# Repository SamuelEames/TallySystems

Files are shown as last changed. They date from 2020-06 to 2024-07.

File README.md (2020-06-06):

# vMixTally
Tally light system for vMix using Arduino USB MIDI controller, transmitting tally light data to receiver modules on cameras using NRF24L01 radios

## MIDI Map

Notes
* Use midi note value to set colour of LEDs on tally lights

* Channel = 2

Data from vMix
* Preview <Input Number> Note 000-031
* Program <Input Number> Note 100-131
* Streaming

Data from BMD
 * Preview <Input Number>
 * Program <Input Number>
 * AUX 	   <Input Number>

BMD Inputs
1-8
MP 1-2
Col 1-2
FTB

Tally Light Colours
|			| 			| BMD		|			|			|
| --- | --- | --- | --- | --- |
|			|			| No Signal	| Program	| Preview	| AUX
| vMix 		| No Signal	| NA		| Yellow	| Blue 		|
|			| Program	| Yellow	| Red		| Green 	|
|			| Preview	| Blue		| Green		| Off 		|

# Resources
BMD-Arduino interface
https://github.com/mathijsk/Arduino-Library-for-ATEM-Switchers 

Insanely cool company
https://www.skaarhoj.com/various/atem-arduino-case-stories/
https://www.skaarhoj.com/support/manual/

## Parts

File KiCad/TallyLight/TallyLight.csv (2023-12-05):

Source: | C:\Users\samue\OneDrive\Documents\ELECTRONICS_PROJECTS\TallySystems\KiCad\TallyLight\TallyLight.kicad_sch
Date: | 9/11/2023 0:10:53
Tool: | Eeschema 7.0.5
Generator: | C:\Program Files\KiCad\7.0\bin\scripting\plugins/bom_csv_grouped_by_value.py
Component Count: | 48
Collated Components:
Item | Qty | Reference(s) | Value | LibPart | Footprint | Datasheet | DNP | Description | Height | Manufacturer_Name | Manufacturer_Part_Number | Mouser Part Number | Mouser Price/Stock
1 | 3 | 3V1, 5V1, LED1 | LED | Device:LED | LED_SMD:LED_0805_2012Metric | ~
2 | 11 | C1, C2, C3, C4, C5, C6, C7, C8, C14, C15, C16 | 104 | SamacSys_Parts:C0805C104M5RACTU | SamacSys_Parts:C0805 | https://content.kemet.com/datasheets/KEM_C1002_X7R_SMD.pdf |  | SMD Comm X7R, Ceramic, 0.1 uF, 20%, 50 VDC, 125 VDC, 125?C, -55?C, X7R, SMD, MLCC, Temperature Stable, Class II, 2.5 % , 10 GOhms, 11 mg, 0805, 2mm, 1.25mm, 0.78mm, 0.75mm, 0.5mm, 4000, 78 Weeks, 80 | 1.1 | KEMET | C0805C104M5RACTU | 80-C0805C104M5R | https://www.mouser.co.uk/ProductDetail/KEMET/C0805C104M5RACTU?qs=VOOUd%252Bza08qHu13WgNByHQ%3D%3D
3 | 2 | C9, C11 | 105 | SamacSys_Parts:CL21B105KBFNNNG | SamacSys_Parts:CAPC2012X135N | https://datasheet.datasheetarchive.com/originals/distributors/Datasheets-DGA8/2478774.pdf |  | Cap Ceramic 1uF 50V X7R 10% Pad SMD 0805 125C T/R | 1.35 | Samsung Electro-Mechanics | CL21B105KBFNNNG | 187-CL21B105KBFNNNG | https://www.mouser.co.uk/ProductDetail/Samsung-Electro-Mechanics/CL21B105KBFNNNG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
4 | 1 | C10 | 471 | SamacSys_Parts:C0805C471K5RACTU | SamacSys_Parts:C0805 | https://content.kemet.com/datasheets/KEM_C1002_X7R_SMD.pdf |  | SMD Comm X7R, Ceramic, 470 pF, 10%, 50 VDC, 125 VDC, 125?C, -55?C, X7R, SMD, MLCC, Temperature Stable, Class II, 2.5 % , 100 GOhms, 11 mg, 0805, 2mm, 1.25mm, 0.78mm, 0.75mm, 0.5mm, 4000, 78 Weeks, 80 | 1.1 | KEMET | C0805C471K5RACTU | 80-C0805C471K5R | https://www.mouser.co.uk/ProductDetail/KEMET/C0805C471K5RACTU?qs=zLJ08xwufm6Yml9V9rLpFw%3D%3D
5 | 2 | C12, C13 | 106 | SamacSys_Parts:GRM188D71A106MA73J | SamacSys_Parts:CAPC1608X90N | https://psearch.en.murata.com/capacitor/product/GRM188D71A106MA73%23.html |  | Capacitor GRM18_0.20 L=1.6mm W=0.8mm T=0.8mm | 0.9 | Murata Electronics | GRM188D71A106MA73J | 81-GRM188D71A106MA3J | https://www.mouser.co.uk/ProductDetail/Murata-Electronics/GRM188D71A106MA73J?qs=hNud%2FORuBR3g0t9KhbQaoQ%3D%3D
6 | 2 | C17, C18 | 22p | SamacSys_Parts:C0805C220K5HACTU | SamacSys_Parts:C0805 | https://content.kemet.com/datasheets/KEM_C1007_X8R_ULTRA_150C_SMD.pdf |  | SMD Comm X8R HT150C, Ceramic, 22 pF, 10%, 50 VDC, 125 VDC, 150C, -55C, X8R, SMD, MLCC, High Temperature, Ultra-Stable, 2.5 % , 100 GOhms, 11 mg, 0805, 2mm, 1.25mm, 0.78mm, 0.75mm, 0.5mm, 4000, 78 Weeks | 1.1 | KEMET | C0805C220K5HACTU | 80-C0805C220K5HACTU | https://www.mouser.co.uk/ProductDetail/KEMET/C0805C220K5HACTU?qs=W0yvOO0ixfEHOdsIsVM%2FuQ%3D%3D
7 | 1 | IC1 | TC1263-3.3VOATR | SamacSys_Parts:TC1263-3.3VOATR | SamacSys_Parts:SOIC127P600X175-8N | http://ww1.microchip.com/downloads/en/DeviceDoc/21374D.pdf |  | LDO Voltage Regulators 500mA Fixed Out Adj | 1.75 | Microchip | TC1263-3.3VOATR | 579-TC1263-3.3VOATR | https://www.mouser.co.uk/ProductDetail/Microchip-Technology/TC1263-33VOATR?qs=JKWmWPM4binFIJC0VNJYCQ%3D%3D
8 | 1 | IC2 | VEML7700-TT | SamacSys_Parts:VEML7700-TT | SamacSys_Parts:VEML7700 | https://www.arrow.com/en/products/veml7700-tt/vishay |  | 16Bit Ambient Light Sensor I2C 6.8x2.3mm |  | Vishay | VEML7700-TT | 78-VEML7700-TT | https://www.mouser.co.uk/ProductDetail/Vishay-Semiconductors/VEML7700-TT?qs=BcfjnG7NVaXdL6DJFdWbdw%3D%3D
9 | 1 | IC3 | ATMEGA328PB-AU | SamacSys_Parts:ATMEGA328PB-AU | SamacSys_Parts:QFP80P900X900X120-32N |  |  | ATMEL - ATMEGA328PB-AU - MCU, 8BIT, ATMEGA, 20MHZ, TQFP-32 | 1.2 | Microchip | ATMEGA328PB-AU | 556-ATMEGA328PB-AU | https://www.mouser.co.uk/ProductDetail/Microchip-Technology/ATMEGA328PB-AU?qs=jy4bLUHv09hbFONgGrqPbw%3D%3D
10 | 1 | J1 | USB4125-GF-A-0190 | SamacSys_Parts:USB4125-GF-A-0190 | SamacSys_Parts:USB4125GFA0190 |  |  | USB Connectors USB C Rec GF RA 6P SMT TH Stakes 1.9mm |  | GCT (GLOBAL CONNECTOR TECHNOLOGY) | USB4125-GF-A-0190 | 640-USB4125-GF-A-190 | https://www.mouser.co.uk/ProductDetail/GCT/USB4125-GF-A-0190?qs=QNEnbhJQKvbCz4hEJBS24w%3D%3D
11 | 1 | J2 | Conn_01x01_Pin | Connector:Conn_01x01_Pin | Connector_PinSocket_2.54mm:PinSocket_1x01_P2.54mm_Vertical | ~
12 | 1 | J3 | Conn_01x06_Pin | Connector:Conn_01x06_Pin | Connector_PinHeader_2.54mm:PinHeader_1x06_P2.54mm_Vertical | ~
13 | 1 | J4 | Conn_01x03_Pin | Connector:Conn_01x03_Pin | Connector_PinHeader_2.54mm:PinHeader_1x03_P2.54mm_Vertical | ~
14 | 1 | Q1 | BSS138DW-7-F | SamacSys_Parts:BSS138DW-7-F | SamacSys_Parts:SOT65P210X110-6N |  |  | MOSFET Dual N-Channel 50V 0.2A SOT363 Diodes Inc BSS138DW-7-F Dual N-channel MOSFET Transistor, 0.2 A, 50 V, 6-Pin SOT-363 | 1.1 | Diodes Inc. | BSS138DW-7-F | 621-BSS138DW-F | https://www.mouser.co.uk/ProductDetail/Diodes-Incorporated/BSS138DW-7-F?qs=rGAXPo9uwV10UlZnPRLyGg%3D%3D
15 | 2 | R1, R2 | 5K1 | Device:R | Samuel_Library:R_0805_2012Metric_Pad1.20x1.40mm_HandSolder | ~
16 | 1 | R3 | 100K | Device:R | Samuel_Library:R_0805_2012Metric_Pad1.20x1.40mm_HandSolder | ~
17 | 1 | R4 | 130R | Device:R | Samuel_Library:R_0805_2012Metric_Pad1.20x1.40mm_HandSolder | ~
18 | 2 | R5, R6 | 300R | Device:R | Samuel_Library:R_0805_2012Metric_Pad1.20x1.40mm_HandSolder | ~
19 | 1 | RN1 | 10K | SamacSys_Parts:YC124-JR-0710KL | SamacSys_Parts:YC124JR0710KL | https://www.yageo.com/upload/media/product/productsearch/datasheet/rchip/PYu-YC_TC_group_51_RoHS_L_9.pdf |  | 10k Ohm +/-5% 62.5mW Power Per Element Isolated 4 Resistor Network/Array +/-200ppm/C 0804, Convex, Long Side Terminals | 0.55 | YAGEO | YC124-JR-0710KL | 603-YC124-JR-0710KL | https://www.mouser.co.uk/ProductDetail/YAGEO/YC124-JR-0710KL?qs=o9qB%2F%252BVTi4UUU%2FolE1vUew%3D%3D
20 | 1 | SET1 | TS02-66-50-BK-260-SCR-D | SamacSys_Parts:TS02-66-50-BK-260-SCR-D | SamacSys_Parts:TS026650BK260SCRD | https://www.cuidevices.com/product/resource/ts02.pdf |  | Tactile Switches 6 x 6 mm, 5 mm Act Height, 260 gf, Black, Short Crimped, Through Hole, SPST, | 5.2 | CUI Devices | TS02-66-50-BK-260-SCR-D | 179-TS026650BK260SCR | https://www.mouser.co.uk/ProductDetail/CUI-Devices/TS02-66-50-BK-260-SCR-D?qs=A6eO%252BMLsxmQtNldP04biKA%3D%3D
21 | 1 | TALLY#1 | SD-1210 | SamacSys_Parts:SD-1210 | SamacSys_Parts:SD1210 | https://www.mouser.ch/datasheet/2/972/sd_1000_26sd_2000-1827479.pdf |  | Coded Rotary Switches dip rotary code hex, real code, top adj. with + slot | 4.2 | NIDEC COPAL | SD-1210 | 229-SD-1210 | https://www.mouser.co.uk/ProductDetail/Nidec-Copal/SD-1210?qs=XeJtXLiO41R8TV%2F4jbbpgQ%3D%3D
22 | 1 | U1 | LED 1 | Samuel_Library:SK6812_SIDE-A | Samuel_Library:SK6812_SIDE-A
23 | 1 | U2 | LED 2 | Samuel_Library:SK6812_SIDE-A | Samuel_Library:SK6812_SIDE-A
24 | 1 | U3 | LED 3 | Samuel_Library:SK6812_SIDE-A | Samuel_Library:SK6812_SIDE-A
25 | 1 | U4 | LED 4 | Samuel_Library:SK6812_SIDE-A | Samuel_Library:SK6812_SIDE-A
26 | 1 | U5 | LED 5 | Samuel_Library:SK6812_SIDE-A | Samuel_Library:SK6812_SIDE-A
27 | 1 | U6 | LED 6 | Samuel_Library:SK6812_SIDE-A | Samuel_Library:SK6812_SIDE-A
28 | 1 | U7 | LED 7 | Samuel_Library:SK6812_SIDE-A | Samuel_Library:SK6812_SIDE-A
29 | 1 | U8 | LED 8 | Samuel_Library:SK6812_SIDE-A | Samuel_Library:SK6812_SIDE-A
30 | 1 | U9 | NRF24L01 | MySensors:NRF24L01 | MySensors:NRF24L01-SMD
31 | 1 | Y1 | 16M | SamacSys_Parts:ABLS-16.000MHz-16-A-4-H-T | SamacSys_Parts:ABLS | https://abracon.com/Resonators/abls.pdf |  | Oscillator MEMS 120MHz +/-10ppm (Stability) 15pF LVCMOS 55% 1.8V/2.5V/3.3V Automotive 4-Pin QFN SMD T/R |  | ABRACON | ABLS-16.000MHz-16-A-4-H-T | 815-LS16000MHZ16A4HT | https://www.mouser.co.uk/ProductDetail/ABRACON/ABLS-16.000MHZ-16-A-4-H-T?qs=vLWxofP3U2z6hhU1at4Vrw%3D%3D

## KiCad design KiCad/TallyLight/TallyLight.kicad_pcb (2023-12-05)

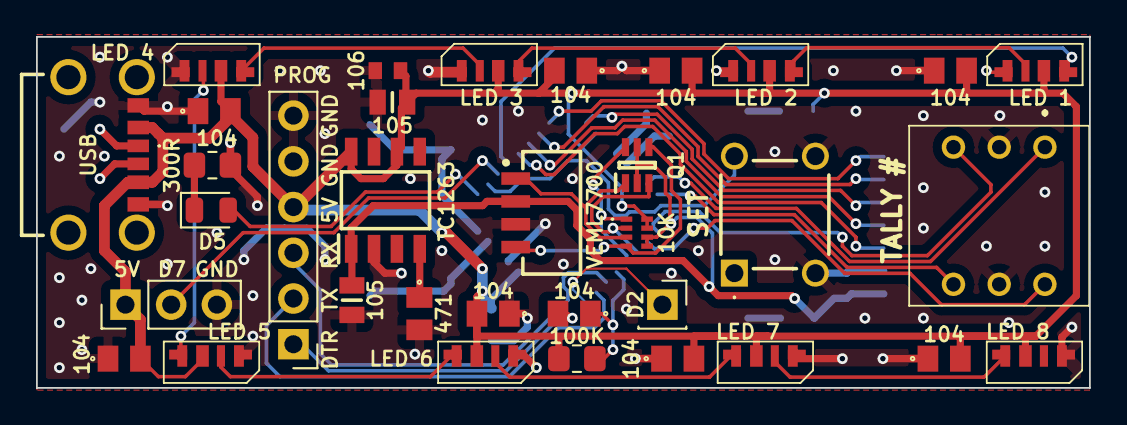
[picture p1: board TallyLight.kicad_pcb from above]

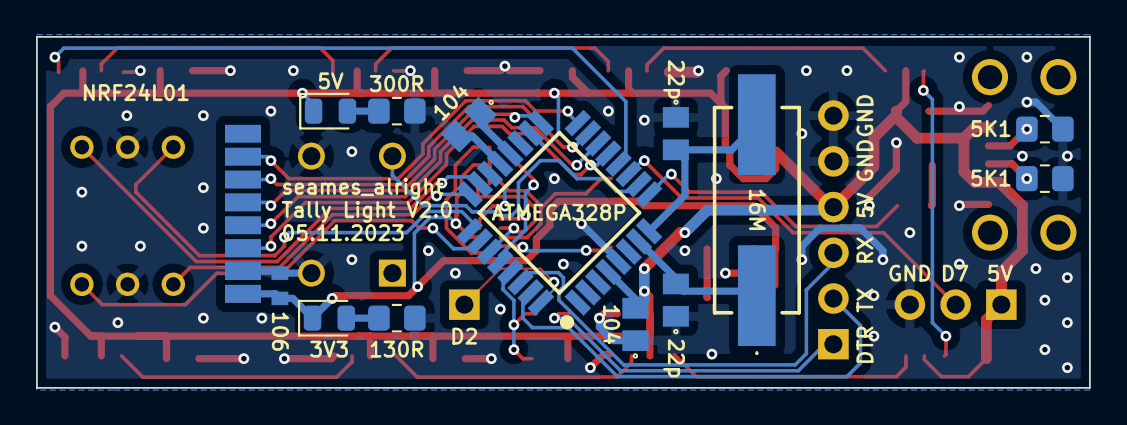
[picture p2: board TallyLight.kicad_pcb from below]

Board: 2 copper layers, 58.5 x 19.5 mm, 48 parts (14 on the bottom side), 41 nets.

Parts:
3V3, 5V: LED; LED_0805_2012Metric
16M: 16M; ABLS
ATMEGA328P: ATMEGA328PB-AU; QFP80P900X900X120-32N
C1, C2, C3, C4, C5, C6, C7, C8, C14, C15, C16: 104; C0805
C9, C11: 105; CAPC2012X135N
C10: 471; C0805
C12, C13: 106; CAPC1608X90N
C17, C18: 22p; C0805
D2: Conn_01x01_Pin; PinSocket_1x01_P2.54mm_Vertical
D5: LED; LED_0805_2012Metric
J4: Conn_01x03_Pin; PinHeader_1x03_P2.54mm_Vertical
NRF24L01: NRF24L01; NRF24L01-SMD
PROG: Conn_01x06_Pin; PinHeader_1x06_P2.54mm_Vertical
Q1: BSS138DW-7-F; SOT65P210X110-6N
R1, R2: 5K1; R_0805_2012Metric_Pad1.20x1.40mm_HandSolder
R3: 100K; R_0805_2012Metric_Pad1.20x1.40mm_HandSolder
R4: 130R; R_0805_2012Metric_Pad1.20x1.40mm_HandSolder
R5, R6: 300R; R_0805_2012Metric_Pad1.20x1.40mm_HandSolder
RN1: 10K; YC124JR0710KL
SET: TS02-66-50-BK-260-SCR-D; TS026650BK260SCRD
TALLY #: SD-1210; SD1210
TC1263: TC1263-3.3VOATR; SOIC127P600X175-8N
U1: LED 1; SK6812_SIDE-A
U2: LED 2; SK6812_SIDE-A
U3: LED 3; SK6812_SIDE-A
U4: LED 4; SK6812_SIDE-A
U5: LED 5; SK6812_SIDE-A
U6: LED 6; SK6812_SIDE-A
U7: LED 7; SK6812_SIDE-A
U8: LED 8; SK6812_SIDE-A
USB: USB4125-GF-A-0190; USB4125GFA0190
VEML7700: VEML7700-TT; VEML7700

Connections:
+3V3: 3V3.1 (K), C9.1, C12.1, NRF24L01.2 (VCC), Q1.2 (G2), Q1.5 (G1), RN1.5, RN1.6, TC1263.1 (VOUT), VEML7700.2 (VDD)
+5V: 5V.1 (K), ATMEGA328P.4 (VCC), ATMEGA328P.18 (AVCC), C1.2, C2.2, C3.2, C4.2, C5.2, C6.2, C7.2, C8.2, C11.1, C13.1, C14.2, J4.1, PROG.4, R3.1, RN1.7, RN1.8, TC1263.6 (~SHDN), TC1263.8 (VIN), U1.2 (VDD), U2.2 (VDD), U3.2 (VDD), U4.2 (VDD), U5.2 (VDD), U6.2 (VDD), U7.2 (VDD), U8.2 (VDD), USB.A9 (VBUS_1), USB.B9 (VBUS_2)
/BTN: ATMEGA328P.10 ((OC0A/PTCXY/AIN0)_PD6), SET.2 (NO_2)
/DTR: C15.2, PROG.1
/HEX_1: ATMEGA328P.23 (PC0_(ADC0/PTCY/MISO1)), TALLY #.1
/HEX_2: ATMEGA328P.24 (PC1_(ADC1/PTCY/SCK1)), TALLY #.2
/HEX_4: ATMEGA328P.25 (PC2_(ADC2/PTCY)), TALLY #.4
/HEX_8: ATMEGA328P.26 (PC3_(ADC3/PTCY)), TALLY #.8
/LED: ATMEGA328P.9 ((OC0B/T1/PTCXY)_PD5), D5.2 (A)
/LED_DATA: ATMEGA328P.12 ((ICP1/CLKO/PTCXY)_PB0), U1.1 (DIN)
/LED_DATA_2: ATMEGA328P.11 ((PTCXY/AIN1)_PD7), J4.2
/MISO: ATMEGA328P.16 ((MISO0/RXD1/PTCXY)_PB4), NRF24L01.7 (MISO)
/MOSI: ATMEGA328P.15 ((MOSI0/TXD1/OC2A/PTCXY)_PB3), NRF24L01.6 (MOSI)
/RF_CE: ATMEGA328P.13 ((OC1A/PTCXY)_PB1), NRF24L01.3 (CE)
/RF_CSN: ATMEGA328P.14 ((~SS0/OC1B/PTCXY)_PB2), NRF24L01.4 (CSN)
/RST: ATMEGA328P.29 (PC6_(~RESET)), C15.1, R3.2
/RXI: ATMEGA328P.30 (PD0_(PTCXY/OC3A/RXD0)), PROG.3
/SCK: ATMEGA328P.17 (PB5_(PTCXY/XCK0/SCK0)), NRF24L01.5 (SCK)
/SCL: ATMEGA328P.28 (PC5_(ADC5/PTCY/SCL0)), Q1.6 (D2), RN1.1
/SCL_3V: Q1.1 (S2), RN1.3, VEML7700.1 (SCL)
/SDA: ATMEGA328P.27 (PC4_(ADC4/PTCY/SDA0)), Q1.3 (D1), RN1.2
/SDA_3V: Q1.4 (S1), RN1.4, VEML7700.4 (SDA)
/TXO: ATMEGA328P.31 (PD1_(PTCXY/OC4A/TXD0)), PROG.2
/XTAL1: 16M.1, ATMEGA328P.7 ((XTAL1/TOSC1)_PB6), C17.2
/XTAL2: 16M.2, ATMEGA328P.8 ((XTAL2/TOSC2)_PB7), C18.2
GND: ATMEGA328P.5 (GND_1), ATMEGA328P.21 (GND_2), C1.1, C2.1, C3.1, C4.1, C5.1, C6.1, C7.1, C8.1, C9.2, C10.2, C11.2, C12.2, C13.2, C14.1, C16.2, C17.1, C18.1, J4.3, NRF24L01.1 (GND), PROG.5, PROG.6, R1.2, R2.2, R4.1, R5.1, R6.1, SET.3 (COM_1), SET.4 (COM_2), TALLY #.C1, TALLY #.C2, TC1263.2 (GND), U1.4 (GND), U2.4 (GND), U3.4 (GND), U4.4 (GND), U5.4 (GND), U6.4 (GND), U7.4 (GND), U8.4 (GND), USB.A12 (GND_1), USB.B12 (GND_2), VEML7700.3 (GND)
unnamed: 3V3.2 (A), R4.2
unnamed: 5V.2 (A), R5.2
unnamed: C10.1, TC1263.4 (BYPASS)
unnamed: ATMEGA328P.20 (AREF), C16.1
unnamed: ATMEGA328P.32 (PD2_(PTCXY/INT0/OC3B/OC4B)), D2.1
unnamed: R1.1, USB.A5 (CC1)
unnamed: R2.1, USB.B5 (CC2)
unnamed: D5.1 (K), R6.2
unnamed: U1.3 (DOUT), U2.1 (DIN)
unnamed: U2.3 (DOUT), U3.1 (DIN)
unnamed: U3.3 (DOUT), U4.1 (DIN)
unnamed: U4.3 (DOUT), U5.1 (DIN)
unnamed: U5.3 (DOUT), U6.1 (DIN)
unnamed: U6.3 (DOUT), U7.1 (DIN)
unnamed: U7.3 (DOUT), U8.1 (DIN)

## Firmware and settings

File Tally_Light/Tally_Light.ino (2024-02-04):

/* Tally Light

11/10/2023 - started major updates!
  * TODO
    * DONE! - Hex switch to select tally number
    * Light sensor to set brightness automatically
    * Button to set channel
      * Hold button while powering on, then use hex switch to select channel.
      * Channel is saved to EEPROM 10s after no changes
      * Either power cycle to get out of settings mode, OR automatically restart after the 10s
    * When on tally '0' show pattern on LEDs each time signal is received

  * Changed MCU to save costs on units - using Atmega328 instead of Atmega32u4


TODO 
  * Add pixel output for optional tally light up number block on top of camera
      * Or it could just use the same output and override the original one, like how headphone ports switch inhibit speakers when headphones are used
      * Be careful not to short out PSU with whatever connection is used though.



*/



// SETUP DEBUG MESSAGES
// #define DEBUG   //If you comment this line, the DPRINT & DPRINTLN lines are defined as blank.
#ifdef DEBUG
  #define DPRINT(...)   Serial.print(__VA_ARGS__)   //DPRINT is a macro, debug print
  #define DPRINTLN(...) Serial.println(__VA_ARGS__) //DPRINTLN is a macro, debug print with new line
#else
  #define DPRINT(...)                       //now defines a blank line
  #define DPRINTLN(...)                     //now defines a blank line
#endif


#include "FastLED.h"
#include "RF24.h"
#include "ENUMVars.h"
#include "Adafruit_VEML7700.h"


///////////////////////// IO /////////////////////////

// ///////////////////////// Atmega32u4 
// #define RF_CSN_PIN    18
// #define RF_CE_PIN     19

// #define LED_F_PIN     20
// #define LED_B_PIN     21


///////////////////////// Atmega328 
// Radio
#define RF_CE_PIN     9     // 13 - PB1
#define RF_CSN_PIN    10    // 14 - PB2
// SCK  - 17 PB5
// MOSI - 15 PB3
// MISO - 16 PB4

// Pixels
#define LED_PIN       8

// BCD Switch         NOTE: these are read direct from the PINC register in the MY_TALLY_ID macro
#define BCD_1         14    // 26 - PC0
#define BCD_2         15    // 25 - PC1
#define BCD_4         16    // 24 - PC2
#define BCD_8         17    // 23 - PC3

#define BTN_PIN       6

// Outputs
#define PIN_PREV    1
#define PIN_PROG    0

// Light Sensor
// SCL -- 19 - 28 PC5
// SDA -- 18 - 27 PC4




//////////////////// RF Variables ////////////////////
RF24 radio(RF_CE_PIN, RF_CSN_PIN);

uint8_t RF_address[] = "TALY0";

#define MY_TALLY_ID (~PINC & 0x0F)    // Returns current tally number according to BCD switch

uint16_t tallyState_RAW[3];           // Tally flags (1-15, 0 is unused), [0] Prev, [1] Prog, [3] ISO

#define RF_TIMEOUT  5000              // (ms) timeout period for receiving data

#define NUM_LEDS    8
CRGB leds[NUM_LEDS];

#define COL_RED     0xFF0000
#define COL_ORANGE  0xFF2800
#define COL_YELLOW  0xFF8F00
#define COL_GREEN   0x00FF00
#define COL_BLUE    0x0000FF
#define COL_PURPLE  0xB600FF
#define COL_WHITE   0xFFFF7F
#define COL_BLACK   0x000000

#define COL_TAL_RF  0xFF0000
#define COL_TAL_RB  0x3F0000
#define COL_TAL_GB  0x003F00

//////////////////// LUX SENSOR ////////////////////
Adafruit_VEML7700 veml = Adafruit_VEML7700();

#define MAX_LUX     1000          // Lux Level at which LEDs are set to their brightest
#define MIN_LED_BRIGHTNESS  5     // Minimum brightness LEDs are set to 
#define LUX_REFRESH 1000          // (ms) Interval which brightness is adjusted at




void setup() 
{
  // Setup the things - does codes on LEDs to indicate progress as follows - lights an LED purple as each step is completed
      // LED 0 - Pixel Setup
      // LED 1 - Input Setup
      // LED 2 - Lux sensor setup - pauses on red colour for a second if lux sensor not found
      // LED 3 - NRF24L01 - halts on red if error starting radio
      // If debug enabled, steps yellow LEDs until connection is made via serial


  // Setup Pixel LEDs
  FastLED.addLeds<WS2812B, LED_PIN, GRB>(leds, NUM_LEDS);
  FastLED.setBrightness(MIN_LED_BRIGHTNESS);
  fill_solid(leds, NUM_LEDS, 0x000000);

  #ifdef DEBUG
    Serial.begin(115200);
    while (!Serial)
      timeoutLEDS(COL_YELLOW);      // Waiting for serial connection
  #endif

  leds[0] = COL_PURPLE;
  FastLED.show();


  // Input setup  
  pinMode(BCD_1, INPUT_PULLUP);
  pinMode(BCD_2, INPUT_PULLUP);
  pinMode(BCD_4, INPUT_PULLUP);
  pinMode(BCD_8, INPUT_PULLUP);

  pinMode(BTN_PIN, INPUT_PULLUP);

  leds[1] = COL_PURPLE;
  FastLED.show();

  if (!veml.begin()) 
  {
    DPRINTLN("Light sensor not found");

    leds[2] = COL_RED;
    FastLED.show();
    delay(1000);
  }

  leds[2] = COL_PURPLE;
  FastLED.show();


  if (!radio.begin())
  {
    DPRINTLN("NRF24L01 not found");

    leds[3] = COL_RED;
    FastLED.show();

    while (1) {}  // No point in continuing because the radio is a critical part of this program
  }
  radio.setChannel(108);              // Keep out of way of common wifi frequencies = 2.4GHz + 0.108 GHz = 2.508GHz
  radio.setPALevel(RF24_PA_MAX);      // Let's make this powerful... later (RF24_PA_MAX)
  radio.setDataRate( RF24_250KBPS );  // Use low bitrate to be more reliable.. I think??
  radio.setAutoAck(false);            // Don't acknowledge messages
  radio.openReadingPipe(0, RF_address); // All messages read on port 0
  radio.startListening();

  leds[3] = COL_PURPLE;
  FastLED.show();             

  DPRINT(F("MyAddress = "));
  DPRINTLN(MY_TALLY_ID);

  if (!digitalRead(BTN_PIN))
  {
    DPRINTLN("SETUP MODE");
    fill_solid(leds, NUM_LEDS, COL_WHITE);
    FastLED.show();

    while(1) // Stay in setup mode until power cycle (TODO - jump out of it if no changes made in a while)
    {}
  }

}


void loop() 
{
  static uint8_t myTallyID_last = MY_TALLY_ID;
  static uint32_t lastRFTime = millis();

  if (CheckRF())      // Check for new messages and update LEDs accordingly
  {
    LightLEDs();
    lastRFTime = millis();
  }

  // Update LEDs instantly if MY_TALLY_ID has changed
  if (MY_TALLY_ID != myTallyID_last)
  {
    DPRINT("TallyNum changed from ");
    DPRINT(myTallyID_last);
    DPRINT("\t to ");
    DPRINTLN(MY_TALLY_ID);

    LightLEDs();
    myTallyID_last = MY_TALLY_ID;
  }

  // Set brightness from light sensor
  checkRoomLux();

  if (millis() < lastRFTime)               // Millis() wrapped around - restart timer
    lastRFTime = millis();

  if (lastRFTime + RF_TIMEOUT < millis())   // Show LED timeout pattern if we haven't received RF data in a while
    timeoutLEDS(COL_BLUE);
  
}


void LightLEDs()
{
  // Lights up LEDs on tally box according to tally data
  
  // Clear LED colours
  fill_solid(leds, NUM_LEDS, COL_BLACK);
  digitalWrite(PIN_PREV, LOW);
  digitalWrite(PIN_PROG, LOW);

  if ( tallyState_RAW[0] & (1 << MY_TALLY_ID) ) // IF PREVIEW
  {
    fill_solid(leds, NUM_LEDS/2, COL_GREEN);
    // digitalWrite(PIN_PREV, HIGH);
  }

  if ( tallyState_RAW[1] & (1 << MY_TALLY_ID) )    // IF PROGRAM
  {
    fill_solid(leds, NUM_LEDS, COL_RED);
    digitalWrite(PIN_PROG, HIGH);
  }

  if ( tallyState_RAW[2] & (1 << MY_TALLY_ID) )  // IF ISO
  {
    // If also prev or program, only light half the back LEDs yellow
    if ( (tallyState_RAW[0] & (1 << MY_TALLY_ID)) || (tallyState_RAW[1] & (1 << MY_TALLY_ID)) )
      fill_solid(leds, NUM_LEDS/4, COL_YELLOW);
    else
      fill_solid(leds, NUM_LEDS/2, COL_YELLOW);

    digitalWrite(PIN_PROG, HIGH);
  }

  FastLED.show();
  return;
}


void timeoutLEDS(uint32_t led_col)
{
  // Steps blue across back LEDs 
  static uint32_t lastStepTime = millis();
  static uint8_t stepNum = 0;
  const uint16_t stepTime = 500;            // time 

  if (millis() < lastStepTime)               // Millis() wrapped around - restart timer
    lastStepTime = millis();

  if (lastStepTime + stepTime < millis()) // Return if timer hasn't elapsed
   lastStepTime = millis();
  else
    return;

  fill_solid(leds, NUM_LEDS, COL_BLACK);

  // Set one LED to blue
  leds[stepNum++] = led_col;

  if (stepNum >= NUM_LEDS/2)
    stepNum = 0;

  FastLED.show();

  return;
}


void checkRoomLux()
{
  // Sets brightness of LEDs based off Lux from sensor
  uint8_t scaledLux;
  static uint32_t lastLuxTime = millis();

  if (millis() < lastLuxTime)               // Millis() wrapped around - restart timer
    lastLuxTime = millis();

  if (lastLuxTime + LUX_REFRESH < millis()) // Return if timer hasn't elapsed
   lastLuxTime = millis();
  else
    return;

  float luxLevel = veml.readLux();

  DPRINT("RAW LUX = ");
  DPRINT(luxLevel);

  if (luxLevel >= MAX_LUX)   // Cap upper end of lux
    luxLevel = MAX_LUX;

  scaledLux = (luxLevel/(float) MAX_LUX) * 255;

  if (scaledLux < MIN_LED_BRIGHTNESS)
    scaledLux = MIN_LED_BRIGHTNESS;

  DPRINT("\tScaled LUX = ");
  DPRINTLN(scaledLux);

  FastLED.setBrightness(scaledLux);
  FastLED.show();

  return;
}


bool CheckRF()
{
  // Checks for updates from controller & updates state accordingly
  bool newMessage = false;

  if (radio.available())    // Read in message
  {
    DPRINT(".");
    radio.read(&tallyState_RAW, sizeof(tallyState_RAW));
    newMessage = true;
  }

  #ifdef DEBUG
    if (newMessage)
    {
      Serial.print("Message Received! = ");
      for (uint8_t i = 0; i < sizeof(tallyState_RAW)/sizeof(tallyState_RAW[0]); ++i)
      {
        Serial.print(tallyState_RAW[i], BIN);
        Serial.print("\t");
      }
      Serial.println();

      Serial.print("MyAddress = ");
      Serial.println(MY_TALLY_ID);
    }
  #endif

  return newMessage;
}

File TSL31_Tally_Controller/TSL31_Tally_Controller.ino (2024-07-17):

/* Tally Controller - reads TSL3.1 UDP Multicast data and broadcasts to tally lights via NRF24L01


TODO
 * Try to improve speed
      * Controller seems to be receiving everything, but tally lights aren't getting every update, so lag behind sometimes
      * Implement brightness

 * Boss level
    * Implement screen and encoder/button knob for setting paremeters
          * IP Address
          * Port Number
          * Brightness (controller LEDs, Front tally lights, back tally lights)
          * ISO Bus number to respond to



RADIO DATA FORMAT
  * Let's transmit the first 16 cameras
  * Each needs 
    * PROG                  = 2x bytes  (bit flags for cameras 0-15)
    * ISO                   = 2x bytes
    * PREV                  = 2x bytes
    * Brightness Front/back = 1x byte   (0-15 Front brightness, 0-15 Back brightness)

  * = 7 bytes total to transmit each time


  Switcher Tally Setup - notes just for me because I keep forgetting them
   * 1-tslumd_1.0
   * Multicast IP 224.0.168.168

   * 1SecUpdate   On      -- Updates one tally every (when idle) rather than dump of everything once a minute
   * ShowUMDIf    On      -- Essential for ISO feature to work
   * ShowBusName  On      -- Not essential, but handy for debugging
   * FSLBL        On      -- I have no idea what this means - it shows '(FS)' on inputs 
   * Center       Off     -- Not sure if this is critical anymore -- centers text, otherwise text is left justified
   * Transport    UDP     -- Important 
   * Port         8903    -- Important


TSL TALLY DATA FORMAT (TSL 3.1)

| HEADER | CONTROL BYTE | DISPLAY DATA |
----------------------------------------------------------------
HEADER (1 Byte)
  Display address (0-126) + 80 hex (control byte and display data will be sent )

CONTROL (1 byte)
  bit 0 = tally 1 ( 1=on, 0=off )
  bit 1 = tally 2 ( 1=on, 0=off )
  bit 2 = tally 3 ( 1=on, 0=off )
  bit 3 = tally 4 ( 1=on, 0=off )
  
  bits 4-5 = brightness data

    bit 4 = 0, bit 5 = 0 (0 brightness)
    bit 4 = 0, bit 5 = 1 (1/7 brightness)
    bit 4 = 1, bit 5 = 0 (1/2 brightness)
    bit 4 = 1, bit 5 = 1 (full brightness)
    
    bit 6 = reserved (clear to 0)
    bit 7 = cleared to 0

DATA (16 bytes)
  16 displayable ASCII characters in the range 20 hex to 7E hex. All 16 characters must be sent.


*/




// SETUP DEBUG MESSAGES
// #define DEBUG   //If you comment this line, the DPRINT & DPRINTLN lines are defined as blank.
#ifdef DEBUG
  #define DPRINT(...)   Serial.print(__VA_ARGS__)   //DPRINT is a macro, debug print
  #define DPRINTLN(...) Serial.println(__VA_ARGS__) //DPRINTLN is a macro, debug print with new line
#else
  #define DPRINT(...)                       //now defines a blank line
  #define DPRINTLN(...)                     //now defines a blank line
#endif


// INCLUDE LIBRARIES
#include <SPI.h>
#include <Ethernet.h>
#include <EthernetUdp.h>
#include "FastLED.h"
#include "RF24.h"

// #include "ENUMVars.h"

///////////////////////// IO /////////////////////////
#define LED_PIN       6
#define RF_CSN_PIN    18
#define RF_CE_PIN     19


//////////////////// Pixel Setup ////////////////////
#define NUM_LEDS      8
CRGB leds[NUM_LEDS]; // Define the array of leds

#define LED_BRIGHTNESS 10

// Colours!
#define COL_RED     0xFF0000
#define COL_ORANGE  0xFF2800
#define COL_YELLOW  0xFF8F00
#define COL_GREEN   0x00FF00
#define COL_BLUE    0x0000FF
#define COL_PURPLE  0xB600FF
#define COL_WHITE   0xFFFF7F
#define COL_BLACK   0x000000



//////////////////// RF Variables ////////////////////
// #define MAX_TALLY_NODES   8               // Note: includes controller as a node (max nodes = 255)

RF24 radio(RF_CE_PIN, RF_CSN_PIN);

uint8_t RF_address[] = "TALY0";

// #define RF_BUFF_LEN 6                     // Number of bytes to transmit / receive -- Prog RGB, Prev RGB
// uint8_t radioBuf_RX[RF_BUFF_LEN];
// uint8_t radioBuf_TX[RF_BUFF_LEN];
bool newRFData = false;                   // True if new data over radio just in


//////////////////// ETHERNET SETUP ////////////////////
byte mac[] = {0xDE, 0xAD, 0xBE, 0xEF, 0xFE, 0xED};    // MAC address of this Ethernet Shield.
EthernetUDP Udp;
IPAddress ip(10, 1, 100, 15);                   // static IP address that Arduino uses to connect to LAN.
IPAddress multicastip(224, 0, 168, 168);        // the Multicast IP to listen on.

uint16_t multicastport = 8903;                  // the Multicast Port to listen on.
char packetBuffer[UDP_TX_PACKET_MAX_SIZE];      // buffer to hold incoming packet.
uint8_t packetSize;                             // Holds size of last UDP message

uint32_t lastEthTime;                           // Time ethernet data was last received
#define TX_ETH_DELAY  20                        // (ms) delay between receving eth data and transmitting radio data 
                                                //  to give ethernet more time for receiving

//////////////////// GLOBAL VARIABLES ////////////////////


#define TALLY_QTY 16                      // Number of tally devices (counting up from 1);
bool newTallyData = false;

uint16_t tallyState_RAW[3];                   // Holds current state of all tally lights

uint8_t tallyText_RAW[16][TALLY_QTY];   // Holds label names associated with each tally on range 1-32


#define tallyBrightness 7                 // Brightness of tally lights on nodes (range 0-15)
#define REFRESH_INTERVAL  100            // (ms) retransimits tally data to nodes when this time elapses from last transmit 
                                            // Note: A transmit is executed every time a change in tally data is detected
uint32_t lastTXTime = 0;                  // Time of last transmit

bool frontTallyON = true;  

bool getTalFromName = true;           // When true, tally data is extracted from looking at the names on inputs going to the selected 'Prev' and 'Prog' busses
                                      // NOTE
                                      //      * names must be of format "CAM X" where 'X' can be a number of 1-3 digits
                                      //      * yellow tally light only works in this mode.
                                      // When false, tally data is taken from input tally data flags (the more common way to get tallies).


bool ISO_enabled = true;
uint8_t broadcastBus = 0x19;  // (25 - ME P/P BKGD) ID of broadcast output (for prog tallies - match to prev number)
uint8_t previewBus   = 0x1A;
// uint8_t broadcastBus = 0x40;    // (64 - MiniMe 1 Bkgnd)
uint8_t ISO_Bus = 0x77;       // (119) Aux MiniMe ID of alternate bus to show tallies on
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

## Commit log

2020-05-16 Reads midi correctly & lights LEDs accordingly
    [ArduinoMidiFastLED.ino, vMixTallyLights.ino]
2020-05-16 Fixed some math errors
    [vMixTallyLights.ino]
2021-10-16 Improved data transmit, tidied up, and broke it
    [vMixTally_Controller.ino, vMixTally_Light.ino]
2022-02-01 Reformat tally data arrays, and broke radios
    [TSL31_Tally_Controller.ino, vMixTally_Light.ino]
2022-02-16 Tidied up & fixed bugs
    [TSL31_Tally_Controller.ino]
2022-11-28 started wired TSL tally controller
2023-05-14 Ross firmware update happened and broke how I was pulling tally data. Not changed to grab bus tally from input names in format 'CAM X'
    [TSL31_Tally_Controller.ino, TSL31_Tally_Wired.ino, Tally_Light.ino]
2023-10-12 started PCB design, implemented BCD switch code
    [TallyLight.kicad_pcb, TallyLight.kicad_sch]
2023-10-28 Tally Light now only uses one pixel LED string
2023-10-28 Updated tally light with dim & timeout functions, added test RF controller
    [TallyLight.kicad_sch]
2023-10-28 Minor Updates to schematic
    [TallyLight.kicad_sch]
2023-12-05 Made a PCB, added error status on LEDs at power up, probably did many more code changes since the last commit
    [SK6812_Side_3DModel.step, TallyLight.csv, TallyLight.kicad_pcb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]
